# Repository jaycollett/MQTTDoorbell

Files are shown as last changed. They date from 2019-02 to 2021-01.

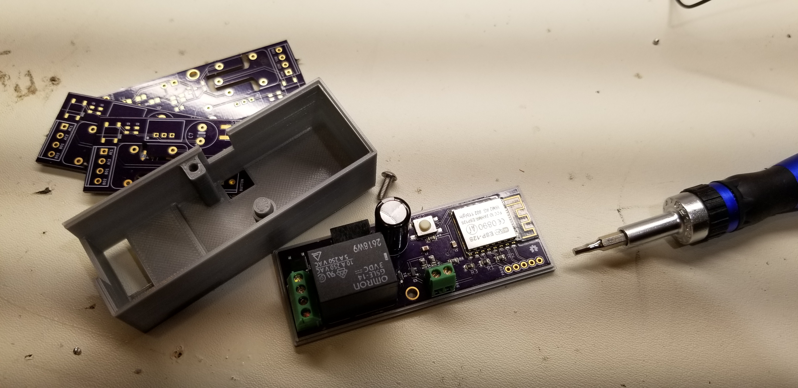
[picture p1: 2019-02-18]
Misc Project Files/Project Enclosure Images/20190217_212452.jpg

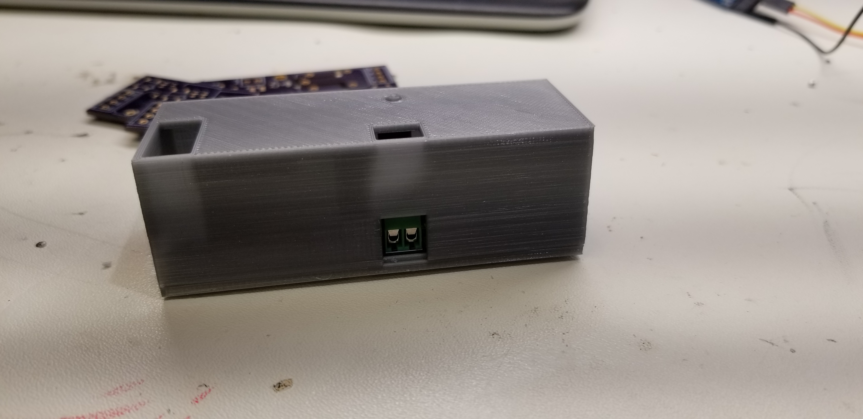
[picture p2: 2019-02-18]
Misc Project Files/Project Enclosure Images/20190217_212348.jpg

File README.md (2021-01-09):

# MQTTDoorbell
 

This repo contains all the project artifacts for my MQTT "smartifier" doorbell module. The module detects a push of the wired doorbell button and triggers a relay to ring the doorbell, the ESP8266 detects this as well and sends a MQTT message to let my HASS.IO server know. From there I trigger automated notifications as well as playing a doorbell MP3 on my Sonos speakers throughout my home.

Please visit my write-up of [this project to get more details](https://www.jaycollett.com/2019/03/a-smarter-doorbell-without-all-the-extras/).

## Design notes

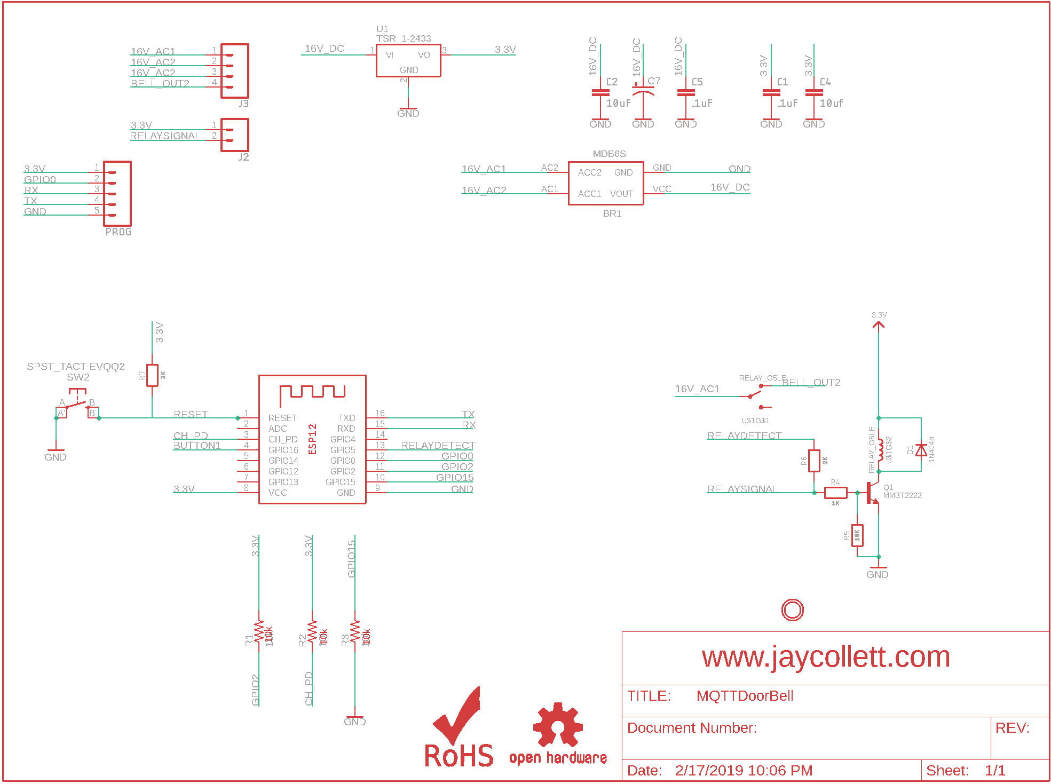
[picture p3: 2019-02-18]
EagleCAD/Schematic.png

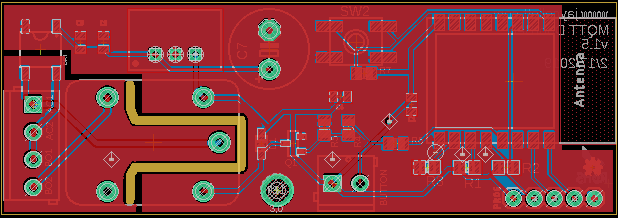
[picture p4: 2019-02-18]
EagleCAD/Board.png

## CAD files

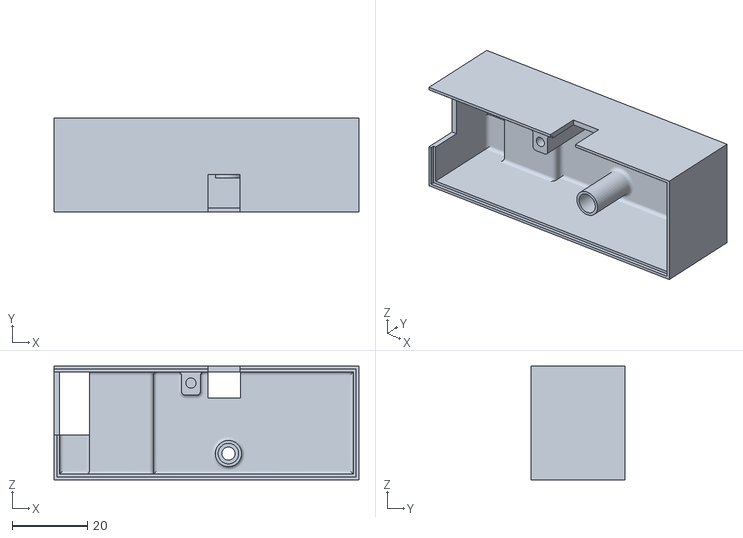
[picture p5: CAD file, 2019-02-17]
Project Enclosure/Top.stl
81.3 x 25.0 x 30.3

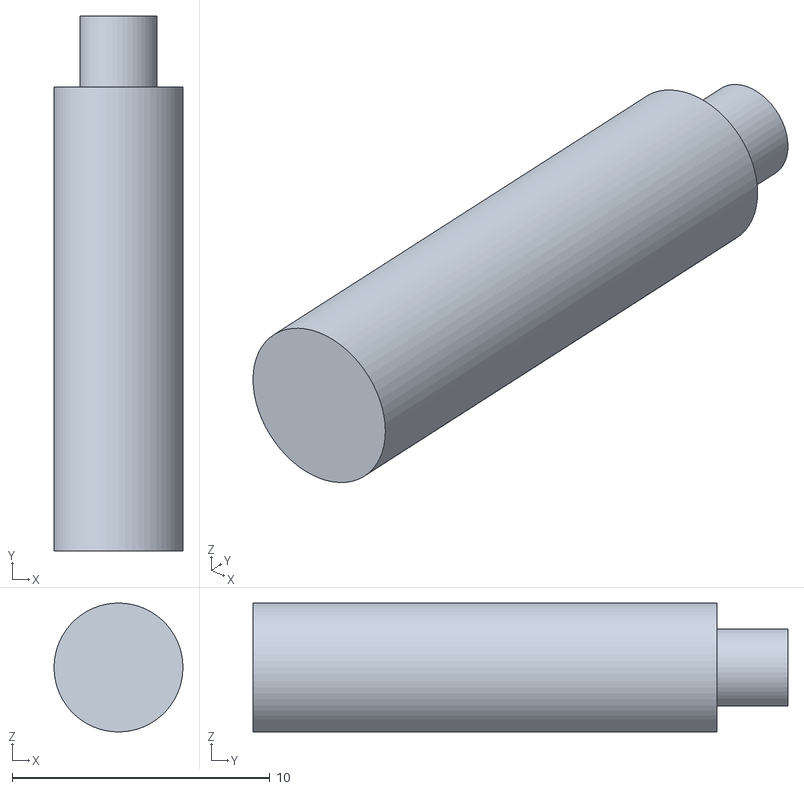
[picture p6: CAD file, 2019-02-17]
Project Enclosure/ResetShaft.stl
5.00 x 20.8 x 5.00

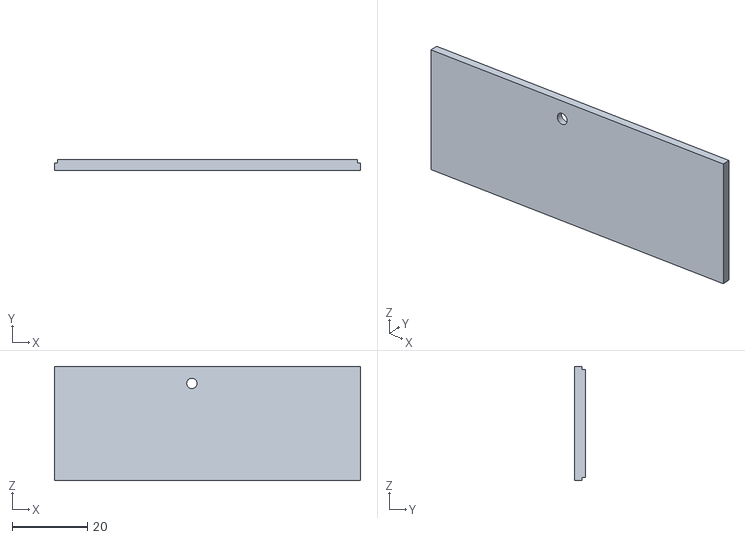
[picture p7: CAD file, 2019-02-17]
Project Enclosure/Bottom.stl
81.3 x 3.00 x 30.3

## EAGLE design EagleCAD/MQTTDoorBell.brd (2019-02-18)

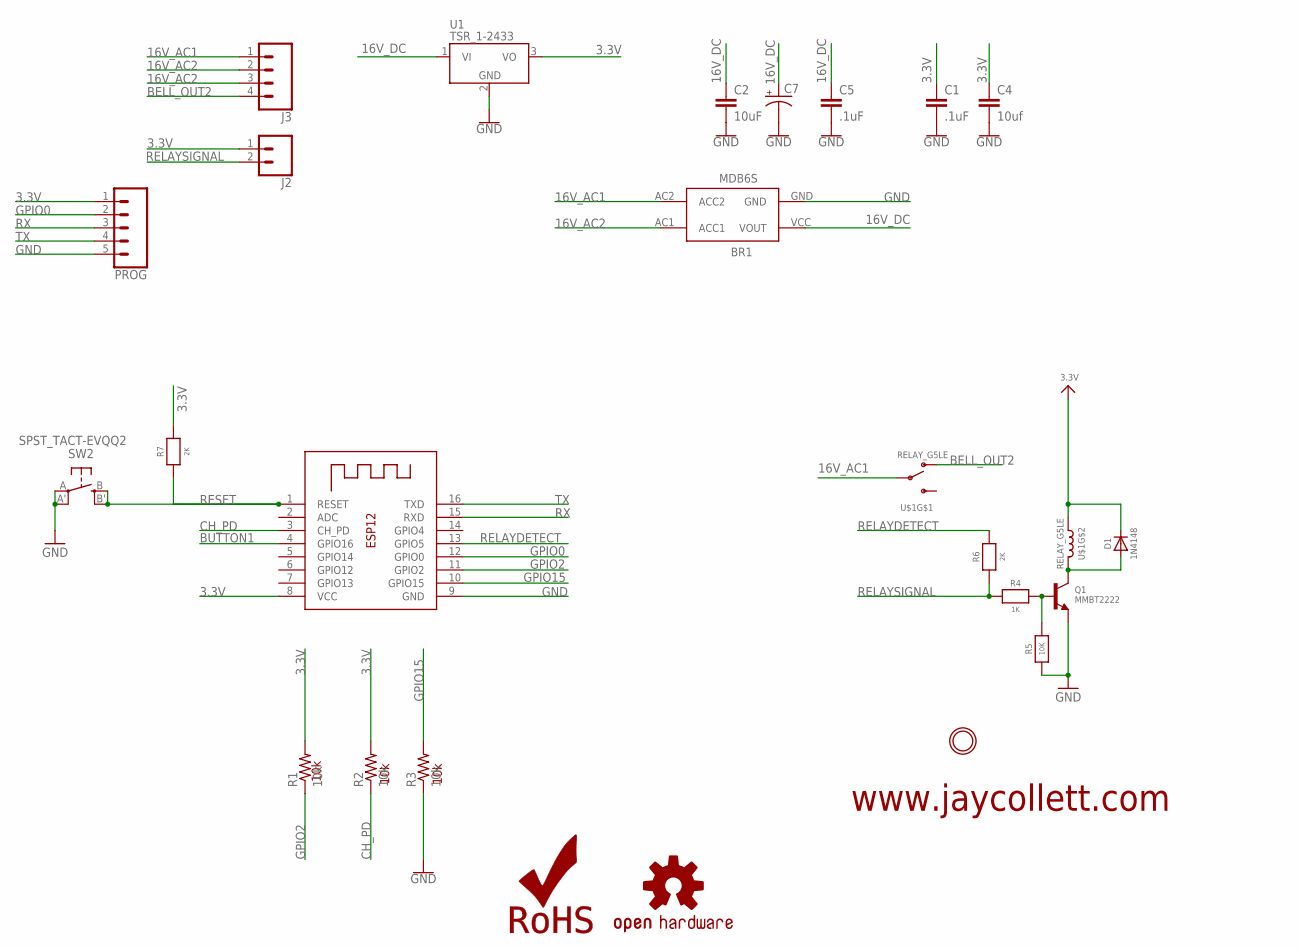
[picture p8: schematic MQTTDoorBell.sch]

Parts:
BR1: MDB6S; MICRO-DIP
C1, C5: .1uF; 0805
C2: 10uF; 0805
C4: 10uf; 0805
C7: CPOL-USE5-10.5; E5-10,5
D1: 1N4148; SOD-323
J2: CONN_023.5MM; SCREWTERMINAL-3.5MM-2
J3: CONN_04SCREW; SCREWTERMINAL-3.5MM-4
LOGO1: OSHW-LOGOMINI; OSHW-LOGO-MINI
LOGO2: ROHS_LOGO; ROHS_LOGO_0.18_IN
PROG: CONN_05; 1X05
Q1: MMBT2222; SOT23-R
R1, R2, R3: 10k; M0805
R4: 1K; 0805-NO
R5: 10K; 0805-NO
R6, R7: 2K; 0805-NO
SW2: SPST_TACT-EVQQ2; EVQ-Q2
U1: TSR_1-2433; TSR-1
U$1: RELAY_G5LE; RELAY_G5LE-1
U$4: MICROBUILDER_MOUNTINGHOLE3.0THIN; MICROBUILDER_MOUNTINGHOLE_3.0_PLATEDTHIN
X1: ESP-12

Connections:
3.3V: C1.1, C4.1, D1.C, J2.1, PROG.1, R1.2, R2.2, R7.2, U1.3 (VO), U$1.2 (1), X1.8 (VCC)
16V_AC1: BR1.AC2 (ACC2), J3.1, U$1.1
16V_AC2: BR1.AC1 (ACC1), J3.2, J3.3
16V_DC: BR1.VCC (VOUT), C2.1, C5.1, C7.+, U1.1 (VI)
BELL_OUT2: J3.4, U$1.3 (O)
BUTTON1: X1.4 (GPIO16)
CH_PD: R2.1, X1.3 (CH_PD)
GND: BR1.GND, C1.2, C2.2, C4.2, C5.2, C7.-, PROG.5, Q1.2 (E), R3.1, R5.1, SW2.A, SW2.A' (P1), U1.2 (GND), X1.9 (GND)
GPIO0: PROG.2, X1.12 (GPIO0)
GPIO2: R1.1, X1.11 (GPIO2)
GPIO15: R3.2, X1.10 (GPIO15)
unnamed: D1.A, Q1.3 (C), U$1.5 (2)
unnamed: Q1.1 (B), R4.2, R5.2
RELAYDETECT: R6.2, X1.13 (GPIO5)
RELAYSIGNAL: J2.2, R4.1, R6.1
RESET: R7.1, SW2.B (S), SW2.B' (S1), X1.1 (RESET)
RX: PROG.3, X1.15 (RXD)
TX: PROG.4, X1.16 (TXD)

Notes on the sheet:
10k
www.jaycollett.com

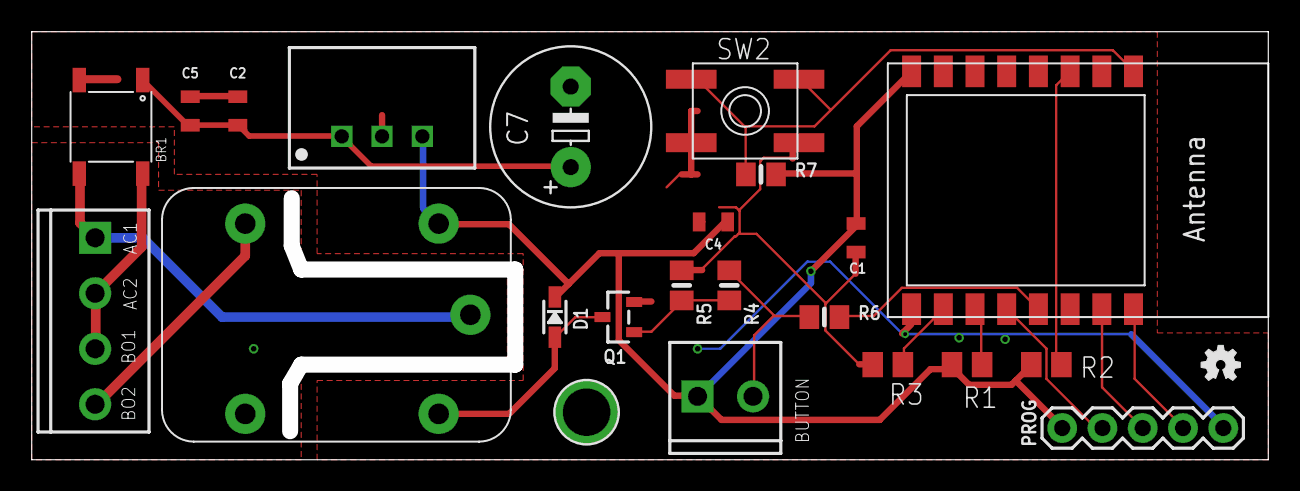
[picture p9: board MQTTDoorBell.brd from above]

Board: 2 copper layers, 78.0 x 27.0 mm, 25 parts (1 on the bottom side), 17 nets.

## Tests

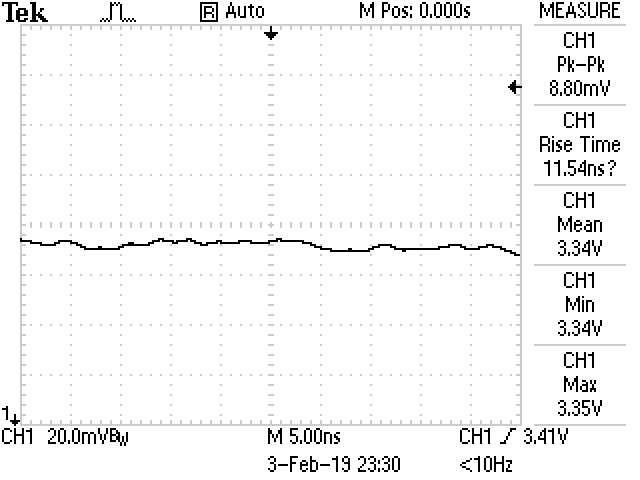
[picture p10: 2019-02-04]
Misc Project Files/RippleMeasurement.JPG

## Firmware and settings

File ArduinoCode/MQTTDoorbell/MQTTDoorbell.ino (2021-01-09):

/**********************************************************************************************
  MQTT Doorbell Module
  Written by: Jay Collett jay.collett AT gmail.com
  Description: This sketch is for my custom PCB which allows for a much smarter
               doorbell without the need for the expensive (and ugly) smart
               doorbells with cameras and such. Simple, and so much cheaper than
               those other "smart" doorbells. You can find more information out
               about this project here:
               https://www.jaycollett.com/2019/02/a-smarter-doorbell-without-all-the-extras/
  Sketch includes unmodified code libraries from the following awesome sources:
      PubSubClient  https://github.com/knolleary/pubsubclient
      ESP8266WiFi   https://github.com/esp8266/Arduino

  This work (excluding external modules/libraries) is licensed under MIT
 ***********************************************************************************************/

#include <ESP8266WiFi.h>
#include <PubSubClient.h>

#define doorbellButtonSensePin 4

#define WIFI_SSID "xxxxxxxx"
#define WIFI_PASS "xxxxxxxxx"
#define MQTT_PORT 1883

int   wifiRetryCount = 0;
char  fmversion[7] = "v1.4";                  // firmware version of this sensor
char  mqtt_server[] = "192.168.0.x";          // MQTT broker IP address
char  mqtt_username[] = "doorbellsensor";     // username for MQTT broker (USE ONE)
char  mqtt_password[] = "xxxxxxxxxxxxxxx";    // password for MQTT broker
char  mqtt_clientid[] = "doorbellSensor";     // client id for connections to MQTT broker

const String HOSTNAME = "doorbellSensor";
const String topic = "binarySensor/doorbell";

IPAddress ip;
WiFiClient WiFiClient;
PubSubClient mqttclient(WiFiClient);

void setup() {

  pinMode(doorbellButtonSensePin, INPUT);
  Serial.begin(115200);
  
  WiFi.hostname(HOSTNAME);
  WiFi.mode(WIFI_STA);
  
  mqttclient.setServer(mqtt_server, MQTT_PORT);
  
  WiFi.begin(WIFI_SSID, WIFI_PASS);
  while (WiFi.status() != WL_CONNECTED) {
    delay(250);
    Serial.print(".");
    if(wifiRetryCount >= 120){ // 250mS delay x 120 iterations = 30 seconds
      ESP.restart();
    }
    wifiRetryCount++;
  }

  wifiRetryCount = 0;
  
  Serial.println("");
  Serial.println("WiFi connected");
  Serial.print("IP address: ");
  Serial.println(WiFi.localIP());

  Serial.println("Calling MQTT Connect");
  MQTT_connect(); // connect to wifi/mqtt as needed
  Serial.println("Pushing initial OFF payload data to MQTT server");
  mqttclient.publish(topic.c_str(), "OFF");
  
}

void loop() {

  
  // loop indefinitely, checking to see if someone has hit the doorbell button
  // doorbell sense pin will go HIGH if the doorbell button is being pushed
  if(digitalRead(doorbellButtonSensePin) == HIGH){
    delay(100); // poor man's debounce
     if(digitalRead(doorbellButtonSensePin) == HIGH){
      mqttclient.publish(topic.c_str(), "ON");
      Serial.println("Somone hit the doorbell, tell the MQTT server...");
      delay(2000); // give time for the payload to register, and prevent silly doorbell mashers from iratating me further...
      mqttclient.publish(topic.c_str(), "OFF");
     }
  }

  if(WiFi.status() != WL_CONNECTED){
    Serial.println("Wifi connection was lost...attempting reconnect.");
    WiFi.begin(WIFI_SSID, WIFI_PASS);
    while(WiFi.status() != WL_CONNECTED){
      delay(250);
      Serial.print(".");
      if(wifiRetryCount >= 120){ // 250mS delay x 120 iterations = 30 seconds
      ESP.restart();
    }
    wifiRetryCount++;
    }
    wifiRetryCount = 0;
  }

  // call this routine each loop
  MQTT_connect();
}



// #############################################################################
//  mqtt Connect function
//  This function connects and reconnects as necessary to the MQTT server and
//  WiFi.
//  Should be called in the loop to ensure connectivity
// #############################################################################
void MQTT_connect() {

  // Stop if already connected.
  if (mqttclient.connected()) {
    return;
  }

  Serial.print("Connecting to MQTT... ");

  // Loop until we're reconnected
  while (!mqttclient.connected()) {
    Serial.print("Attempting MQTT connection...");
    // Attempt to connect
    if (mqttclient.connect(mqtt_clientid, mqtt_username, mqtt_password)) {
      Serial.println("connected");
    } else {
      Serial.print("failed, rc=");
      Serial.print(mqttclient.state());
      Serial.println(" try again in 2 seconds");
      // Wait 2 seconds before retrying
      delay(2000);
    }
  }
  Serial.println("MQTT Connected!");
}

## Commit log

2019-01-09 finish power rectifier and filtering
    [MQTTDoorBell.brd, MQTTDoorBell.sch]
2019-01-09 fix folder structure of project
    [MQTTDoorBell.brd, MQTTDoorBell.sch]
2019-01-11 updating design and starting to structure board
    [MQTTDoorBell.brd, MQTTDoorBell.sch]
2019-01-21 initial commit of eagle files, version 1 of board'
    [MQTTDoorBell.brd, MQTTDoorBell.sch]
2019-01-22 fix polygon issue and add labels'
    [MQTTDoorBell.brd, MQTTDoorBell.sch]
2019-02-04 add new PCB board and schematic, add first draf of firmware
    [MQTTDoorBell.brd, MQTTDoorBell.sch]
2019-02-04 updated issue with detecting doorbell pushes, validated mqtt topic and functionality.
    [MQTTDoorbell.ino]
2019-02-04 add power supply ripple measurement
2019-02-17 added first draft of enclosure
    [Bottom.stl, Top.stl]
2019-02-17 fixing enclosure based on first print issues...
    [Bottom.stl, Top.stl]
2019-02-17 added reset button shaft, tweak screw hole position
    [Bottom.stl, ResetShaft.stl, Top.stl]
2019-02-17 tweaking position of bottom screw hole to align better
    [Bottom.stl]
2019-02-17 tweaked lenght of reset shaft and position of female screw socket
    [ResetShaft.stl, Top.stl]
2019-02-18 adding enclosure images
2019-02-18 fixing critical error with AC power lines to doorbell ringer
    [MQTTDoorBell.brd, MQTTDoorBell.sch]
2021-01-09 rename arduino folder and add travis ci support

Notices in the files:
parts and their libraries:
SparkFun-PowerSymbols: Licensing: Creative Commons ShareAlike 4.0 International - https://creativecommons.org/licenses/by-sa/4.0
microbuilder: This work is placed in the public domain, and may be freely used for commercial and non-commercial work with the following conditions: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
